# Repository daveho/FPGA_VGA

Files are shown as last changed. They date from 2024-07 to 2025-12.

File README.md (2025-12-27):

# FPGA VGA text display

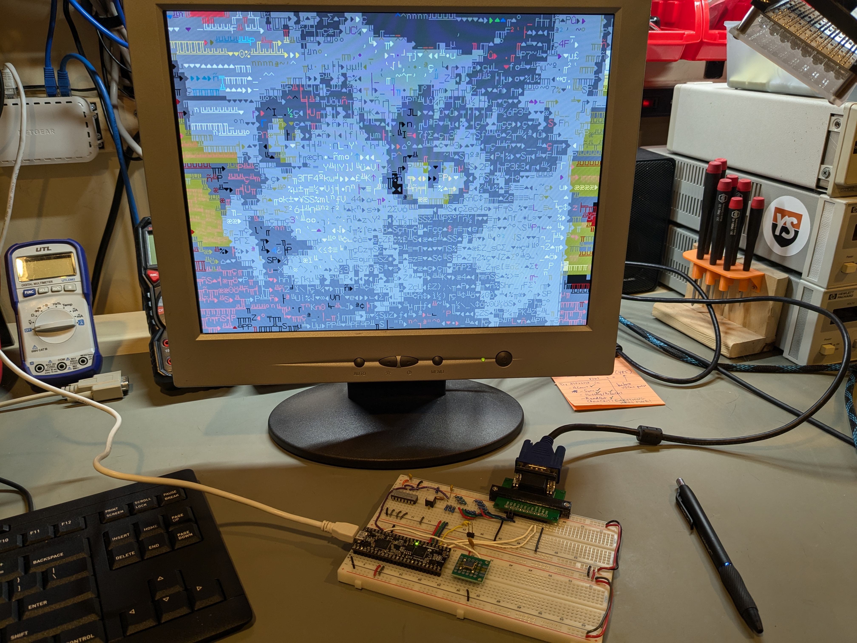
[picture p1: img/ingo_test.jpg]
Photo of FPGA displaying a cat picture rendered with text characters


This is a companion project to the [HW\_VGA](https://github.com/daveho/HW_VGA) project.
Its goal is to implement an 80x30 text display using 640x480 VGA, using more or less
the same approach as the HW\_VGA project, but using a
[Lattice UP5K FPGA](https://www.latticesemi.com/en/Products/FPGAandCPLD/iCE40UltraPlus)
on an [Upduino 3.1](https://tinyvision.ai/products/upduino-v3-1) (or 3.0) board
rather than discrete logic, GALs, and dual port static RAM.

As of December 2025, the design is fully working. I made a video about it:
<https://youtu.be/PG1XWQCylTA>.

The [Schematic](Schematic) directory has a KiCad schematic, and the
[Logic](Logic) directory has the Verilog code for the FPGA. I use
[APIO](https://github.com/FPGAwars/apio) as the front end for the FPGA tools (see my
[blog post about using the Upduino 3 on Linux](https://daveho.github.io/2021/02/07/upduino3-getting-started-on-linux.html)
for details on setting things up.)

Acknowledgment: a viewer of one of my youtube videos recommended
[John Winans's youtube channel](https://www.youtube.com/channel/UCik0xMsb7kSpPUvT2JoJQ1w)
as a good starting point for learning about FPGA development.
His [introduction to simulation](https://youtu.be/xZhl64vHJ-E)
and [his Verilog examples repo](https://github.com/johnwinans/Verilog-Examples) were
incredibly helpful. By applying the techniques covered in the simulation video, I
basically went from having no idea how to simulate designs to being able to write
some halfway-reasonable testbenches in a day or two. Thank you, John!

## Updates

**27-Dec-2025**: A [Youtube video](https://youtu.be/PG1XWQCylTA) about the
project has been posted.

**25-Nov-2025**: the entire design, including a bidirectional
interface to allow the host system to write to and read from VRAM,
appears to be fully working. Video coming soon. Stay tuned!

**20-Nov-2025**: In my previous thoughts about using mirrored VRAM
banks, I had forgotten that I was using 4 KB of block RAM to store
the VGA font. So, the revised plan is mirrored
[5 KB banks](https://github.com/daveho/FPGA_VGA/blob/90469b43ef998fe6521666e1b50f645583a588a4/Logic/vram_5kb.v)
of VRAM.  With the 4 KB of block RAM used for the font, this means
that we're using 2×5 + 4 = 14 KB, which is just under the 15 KB of
block RAM that the Upduino 3's UP5K FPGA has available.

**17-Nov-2025**: Reading an article on Hacker News about an
[FPGA implementation of the IBM PC-XT](https://bit-hack.net/2025/11/10/fpga-based-ibm-pc-xt/)
gave me a really good idea about how to work around the single
read port on the ICE40 Block RAM. The idea is to use two separate
memory banks for the VRAM. Writes from the host system
go to both banks in parallel, so their contents are always identical.
The display rasterization hardware reads from one bank, and the
host system (when it wants to read from VRAM) reads from the other
bank. This would allow for VRAM with one write port and two
fully-independent read ports. One minor difficulty is that the
UP5K device on the Upduino 3 has only 15 KB of VRAM, whereas the
current design uses 8 KB for VRAM. The 80x30 character display
needs only 4800 bytes, so reducing the VRAM to 6 KB would be sufficient.
A 6 KB VRAM bank could be implemented as a 4 KB lower bank and a
2 KB upper bank, mapped into an 8 KB address space with the upper
2 KB bank mirrored twice in the upper 4 KB of addresses. This wouldn't
cause any problems in practice. I'm planning to work on this soon
(maybe over Thanksgiving.)

**8-Aug-2024**: the block RAM in the ICE40 UP5K FPGA used in the
Upduino 3.0/3.1 is not true dual port memory, which will make the host interface
implementation a bit more complicated than I originally envisioned,
since the pixel generator and the host interface will need to share
the single hardware read port to the video memory. So, it may be a while
before I get this working.

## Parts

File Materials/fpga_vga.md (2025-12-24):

---
title: "Episode 5 (Hardware VGA, FPGA edition!)"
aspectratio: 169
colorlinks: true
pandoc-beamer-block:
  - classes: [info]
  - classes: [alert]
    type: alert
pandoc-latex-fontsize:
  - classes: [small]
    size: small
  - classes: [footnotesize]
    size: footnotesize
  - classes: [scriptsize]
    size: scriptsize
header-includes:
  - \usepackage{graphbox}
  - \usepackage[export]{adjustbox}
  - \usepackage[absolute,overlay]{textpos}
  - \usecolortheme{orchid}
---

## Hello again! {.t}

Since 2016, I've been working on a 6809-based microcomputer system `\pause`{=latex}

Summer 2024[^*]: I made a VGA text display using GALs,
dual port static RAMs, and 7400-series logic chips `\pause`{=latex}

Validated the design by simulating in Logisim Evolution `\pause`{=latex}

Got it to work! `\pause`{=latex}

Lots of fun, great learning experience `\pause`{=latex}

*Not very practical* `\pause`{=latex}

* Resulting design has 25 ICs, including two
  52-pin PLCC packages `\pause`{=latex}
* Even using surface mount ICs, very challenging
  to fit on 15cm by 9cm PCB

[^*]: In North America

## Use an FPGA? {.t}

The obvious move would be to use an FPGA `\pause`{=latex}

I've stuggled for *years* to learn FPGAs well enough to make
a display controller `\pause`{=latex}

But...I now had a working design, even if not
an FPGA-based design `\pause`{=latex}

* **Maybe I could translate it to Verilog** `\pause`{=latex}

TL;DR I translated the design to Verilog `\pause`{=latex}

This video: `\pause`{=latex}

* Translating the design to Verilog (the easy parts) `\pause`{=latex}
* Host interface (initially got stuck here, then
  learned about an easy workaround) `\pause`{=latex}
* Demo `\pause`{=latex}
* Next steps `\pause`{=latex}

As always, links to the code and schematic are in the video description.

## Modules {.t}

The original design had 6 modules, each implemented as a GAL
(or two GALs in the case of the pixel generator) and,
where necessary, supporting ICs:

Module              | GAL equations
------------------- | -------------
Horizontal count    | HCntCtrl.pld
Vertical count      | VCntCtrl.pld
Sync generation     | Sync.pld
Readout address gen | ROutCtrl.pld
VRAM                | VRAMCtrl.pld
Pixel gen           | PxGnCtrl.pld, ShiftReg.pld

## Modules (FPGA) {.t}

In the FPGA version of the design, each module is implemented
by one Verilog module:

Module              | GAL equations               | Verilog
------------------- | --------------------------- | -----------
Horizontal count    | HCntCtrl.pld                | hcount.v
Vertical count      | VCntCtrl.pld                | vcount.v
Sync generation     | Sync.pld                    | sync.v
Readout address gen | ROutCtrl.pld                | readout.v
VRAM                | VRAMCtrl.pld                | vram\_mirrored.v
Pixel gen           | PxGnCtrl.pld, ShiftReg.pld  | pixgen.v

`\pause`{=latex} To convert the design to Verilog, I translated the
logic in the original GAL equations and the supporting ICs to
equivalent Verilog constructs in the most direct way possible.

## Converting to Verilog {.t}

General approach to conversion to Verilog:`\pause`{=latex}

Original Design | Verilog
--------------- | --------------- 
GAL registers, 7400 series registers (e.g., 74ALS273) | `reg` instances
Counters (e.g., 74ALS163)            | `reg` instances (Verilog supports addition!)
Clock data into a flip flop          | Nonblocking assignment in `always` block
Dual port RAM (IDT7134)              | Array of 8-bit registers inferred as BRAM
Font ROM (27SF512)                   | 4 KB of pre-initialized block RAM
Module inputs and outputs            | Module inputs and outputs

`\pause `{=latex} Overall, this wasn't too hard!

<!--
* GAL registers and 7400 series registers (e.g., 74ALS273)
  become Verilog registers (`reg` instances) `\pause`{=latex}
* Counters (e.g., 74ALS163) also become Verilog registers
  (because Verilog supports addition, e.g. `addr + 13'd1;`)
  `\pause`{=latex}
* Clocking data into a flip flop becomes a nonblocking assignment
  in an `always @( posedge clk )` block `\pause`{=latex}
* An array of 8-bit vectors with suitable read and write signaling
  will be inferred as block RAM: takes place of dual port static
  RAM (IDT7134) `\pause`{=latex}
* Input and output pins become module input and output wires
-->

## Example: Horizontal Count module {.t}

The horizontal count module counts the horizontal pixels in each
scanline, and generates appropriate timing signal needed by
the vertical count and sync generation modules

In the original implementation:

* 3x 74ALS163 4-bit counters
* GAL for control and timing`\\`{=latex}
  signal generation

`\vfill`{=latex}

Example timing signal: horizontal count`\\`{=latex}
end (true if horizontal count value is at`\\`{=latex}
maximum for scanline)

``` { .scriptsize }
; HCOUNT_END is when HCOUNT=799 (1100011111 binary)
HCEND   = HC9 * HC8 * /HC7 * /HC6 * /HC5 * HC4 * HC3 * HC2 * HC1 * HC0
```

## Example: Horizontal Count module {.t}

In Verilog: define a 12-bit register, reset or increment it as needed:

```verilog { .scriptsize }
reg [11:0] count;

always @(posedge clk) begin
  if ( nrst == 1'b0 ) begin
    // in reset, clear the counter
    count <= 12'd0;
  end else begin
    // not in reset, either advance count by 1 or reset to 0 (if at end of scanline)
    if ( hCountEnd )
      count <= 12'd0;
    else
      count <= count + 12'd1;
  end
end
```

Generating a control signal:

```verilog { .scriptsize }
assign hCountEnd = (count == H_COUNT_END);
```

## Example: Sync module {.t}

The Sync module uses control signals generated by the horizontal
and vertical count modules to generate to generate VGA horizontal
and vertical sync signals, as well as visibility and ``activity''
signals needed by the pixel generator and readout modules.

In the original implementation, it's a single GAL22V10
with registered outputs.

`\vfill`{=latex}

Example timing signal: VGA vertical sync

``` { .scriptsize }
; Vertical sync:
;   - if /NRST is asserted, next VSync should be high
;   - if VEPulse is asserted, next VSync should be high
;   - if neither VBPulse nor VEPulse is asserted, next VSync value
;     should be the same as the current one
VSync.R =   /NRST
          + VEPulse
          + /VBPulse * /VEPulse * VSync
```

## Example: Sync module {.t}

In Verilog, generated outputs are `reg` instances:

```verilog { .scriptsize }
// registers for registered outputs
reg hSyncReg, vSyncReg, hVisReg, vVisReg, vActiveReg;
```

Their contents are updated on each positive clock edge:

```verilog { .scriptsize }
// Note: only showing vSyncReg updates
always @( posedge clk ) begin
  if ( nrst == 1'b0 ) begin
    vSyncReg <= 1'b1; // in reset
  end else begin
    // update vSyncReg if needed
    if ( vBeginPulse ) begin
      vSyncReg <= 1'b0; // begin vsync pulse
    end else if ( vEndPulse ) begin
      vSyncReg <= 1'b1; // end vsync pulse
    end
  end
end
```

## Example: Readout module {.t}

::: columns

:::: column

::::: {.small}
The Readout module generates the VRAM addresses of the character
and attribute values needed to generate the pixels for each visible
scanline.

Original implementation: 3 74ALS163 counters (current address),
2 74ALS273 registers (row begin address), GAL22V10 for control.

* Row of characters = 160 bytes (80 char/attr pairs)
* Characters are 8 pixels wide
* Update readout addr every 4 pixels
* Same sequence of addresses for each
  scanline in a character row

Annoyance: VRAM addresses are 13 bits, so the GAL generates the
MSB of the current address. (Each '163 is only 4 bits.)

:::::

::::

:::: column

`{\ }`{=latex}

::::

:::

## Example: Readout module {.t}

In Verilog, the row begin address and current (readout) address
are just 13 bit registers:

```verilog { .scriptsize }
reg [12:0] rowBeginAddrReg;
reg [12:0] readoutAddrReg;
```

Conditionally update their values according to current control
signal values:

```verilog { .scriptsize }
// Example logic: update rowBeginAddrReg or readoutAddrReg
// at end of scanline (when hSync pulse starts)
if ( vActive & hBeginPulse ) begin
  if ( vCount == 4'b1111 ) begin
    // We've reached the last pixel row in the current character row,
    // so set the row begin address to the current readout address
    // (in order to start the next character row)
    rowBeginAddrReg <= readoutAddrReg;
  end else begin
    // The next pixel row will be part of the same character row,
    // so set the readout address back to the current value of the
    // row begin address register.
    readoutAddrReg <= rowBeginAddrReg;
  end
end
```

## Aside: Verilog test benches {.t}

A viewer of a previous video suggested that I check out
the John's Basement youtube channel to learn about simulation. `\pause`{=latex}

"Test bench" = unit tests for a module (or maybe several modules
working together) `\pause`{=latex}

* Feed in simulated clock and control signals, verify that
  correct output signals are generated `\pause`{=latex}

**This was very, very helpful!** `\pause`{=latex}

I wrote test benches for the Horizontal Count, Vertical Count,
and Readout modules. (Testing Readout indirectly tests Sync.)
This helped me gain confidence that the design would work when
uploaded to the FPGA.

## So, everything was easy, right? {.t}

Well...`\pause `{=latex}**There was one problem**

`\pause `{=latex} The UP5K FPGA's block RAM is`\pause`{=latex}

* Synchronous (not a problem) `\pause`{=latex}
* Not truly dual ported (**big problem!**) `\pause`{=latex}

IDT7134 static RAMs (original design) are true dual port memory `\pause`{=latex}

* Each port can read and write as necessary `\pause`{=latex}
* Rasterization hardware needs to read from VRAM `\pause`{=latex}
* Host system needs to read/write VRAM `\pause`{=latex}
* *No problem, they each use one port* `\pause`{=latex}

UP5K block RAMs have one read port and one write port `\pause`{=latex}

* *Rasterization hardware and host system both want the read port!* `\pause`{=latex}

**What to do?**

## Initial idea: time-share the read port {.t}

Rasterization hardware only reads VRAM 1 out of 4 clock cycles `\pause`{=latex}

Could use the other clock cycles to allow the host system to read `\pause`{=latex}

Not a terrible idea, but significantly complicates the design `\pause`{=latex}

* I made some attempts, but they didn't work `\includegraphics[width=1em]{figures/fpga_vga/angry_face.pdf}`{=latex}

## Genius idea {.t}

*When in doubt, use brute force* — Ken Thompson `\pause`{=latex}

When reading Hacker News I saw a link to a project to create
an FPGA implementation of the IBM PC-XT `\pause`{=latex}

Awesome idea: maintain two copies of video memory `\pause`{=latex}

* Writes from host system go to both (so they always have
  the same content) `\pause`{=latex}
* Rasterization hardware reads from one copy `\pause`{=latex}
* Host system reads from the other copy `\pause`{=latex}

We get a second read port with minimal effort `\pause`{=latex}

* At the cost of doubling the amount of block RAM used `\pause`{=latex}
* Good tradeoff when the limiting factor is the skill of the
  designer `\includegraphics[width=1.2em]{figures/fpga_vga/laughing.pdf}`{=latex}

## Utilizing block RAM {.t}

The UP5K has 15 KB of block RAM `\pause`{=latex}

We need 4 KB for the font, so 11 KB is left for VRAM `\pause`{=latex}

Original design: 2 x IDT7134, 8 KB total VRAM `\pause`{=latex}

In the FPGA-based design, mirrored 5 KB banks requiring
a total of 10 KB `\pause`{=latex}

* Each 5 KB bank is really 4 KB + 1 KB, with the 1 KB
  mirrored 4 times in the upper 4 KB of VRAM addresses `\pause`{=latex}

Overall, this was pretty easy to implement

* `vram_5kb.v`: Verilog module implementing one 5 KB VRAM bank
* `vram_mirrored.v`: Verilog module using two `vram_5k` instances
  to implement a 5 KB VRAM with one write port and two read ports
  `\pause`{=latex}

The readout and pixel generator modules did not need any modification

## Host system reads and writes {.t}

Now I just needed the actual host interface `\pause`{=latex}

Goal: make the display controller's framebuffer look like a normal
asynchronous static RAM

Signals: `\pause`{=latex}

* Bidirectional 8-bit data bus interface `\pause`{=latex}
* 13-bit address input `\pause`{=latex}
* Read strobe input: assert to read byte from VRAM `\pause`{=latex}
* Write strobe input: assert to write byte to VRAM `\pause`{=latex}

Problem: how does bidirectional I/O work in Verilog?

## Bidirectional I/O {.t}

In an old-school microcomputer system: `\pause`{=latex}

* CPU and all peripheral chips connect to a shared parallel data bus `\pause`{=latex}
* Only the chip that is "talking" actively drives the bus `\pause`{=latex}
* All others "tristate" their connections to the data bus `\pause`{=latex}
* Peripherals have an "output enable" of some sort to tell them when
  they can drive output on the data bus `\pause`{=latex}

FPGAs don't use tristate logic internally (AFAIA) `\pause`{=latex}

Synthesis tools create muxes whenever multiple outputs influence
a single input `\pause`{=latex}

Verilog does have a syntax for tristate logic (e.g., `1'bz` to mean a
"high impedence" logic value) `\pause`{=latex}

* But OSS CAD suite (Yosys, ICEStorm, etc.) doesn't really support Verilog
  tristate logic

## What I needed {.t}

What I needed was `\pause`{=latex}

* If host asserts the write strobe, store the data on the bus
  to VRAM (data bus is input) `\pause`{=latex}
* If host asserts the read strobe, drive one VRAM data byte onto
  the data bus (data bus is output) `\pause`{=latex}

How to tell the synthesis to make this happen? `\pause`{=latex}

Did some initial research, wasn't sure how to proceed

## John's Basement to the rescue again {.t}

Found a video on John's Basement covering the ICE40
`SB_IO` primitive `\pause`{=latex}

* Configures an external pin for I/O, including bidirectional I/O `\pause`{=latex}
* For bidirectional I/O, you specify physical pin and
  output enable, it gives you an input and output

## Implementing the host interface {.t}

`ext_data_bus.v` module: one `SB_IO` instance per data bus pin `\pause`{=latex}

E.g.:

```verilog { .scriptsize }
  SB_IO #(
    .PIN_TYPE(6'b1010_01),
    .PULLUP(1'b1)
  ) ext_pin_0 (
    .PACKAGE_PIN(phys[0]),
    .OUTPUT_ENABLE(outputEnable),
    .D_OUT_0(outToBus[0]),
    .D_IN_0(inFromBus[0])
  );
```

 `\pause `{=latex} Output enable is simply the read strobe! `\pause`{=latex}

Read strobe, write strobe, and data bus directly interface to the VRAM `\pause`{=latex}

VGA dot clock (used for synchronous block RAM reads/writes) is fast,
host access should work as long as there is one dot clock edge
during a bus transfer

## Does it work? {.t}

At this point I had what I thought was a viable host interface `\pause`{=latex}

**Would it actually work?**

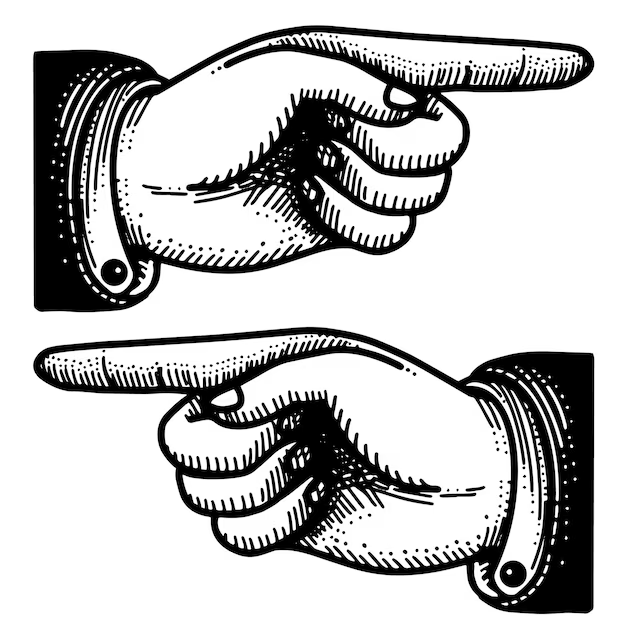
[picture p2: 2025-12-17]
Materials/img/hand.png

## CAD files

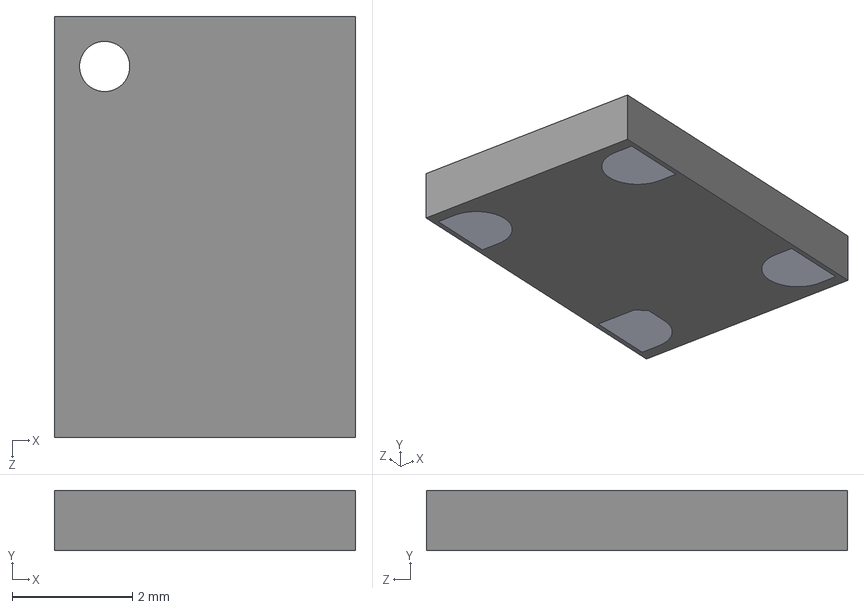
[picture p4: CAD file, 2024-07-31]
Schematic/SIT8208AI-8F-33E-14.745600Y.step
5.00 x 1.00 x 7.00 mm

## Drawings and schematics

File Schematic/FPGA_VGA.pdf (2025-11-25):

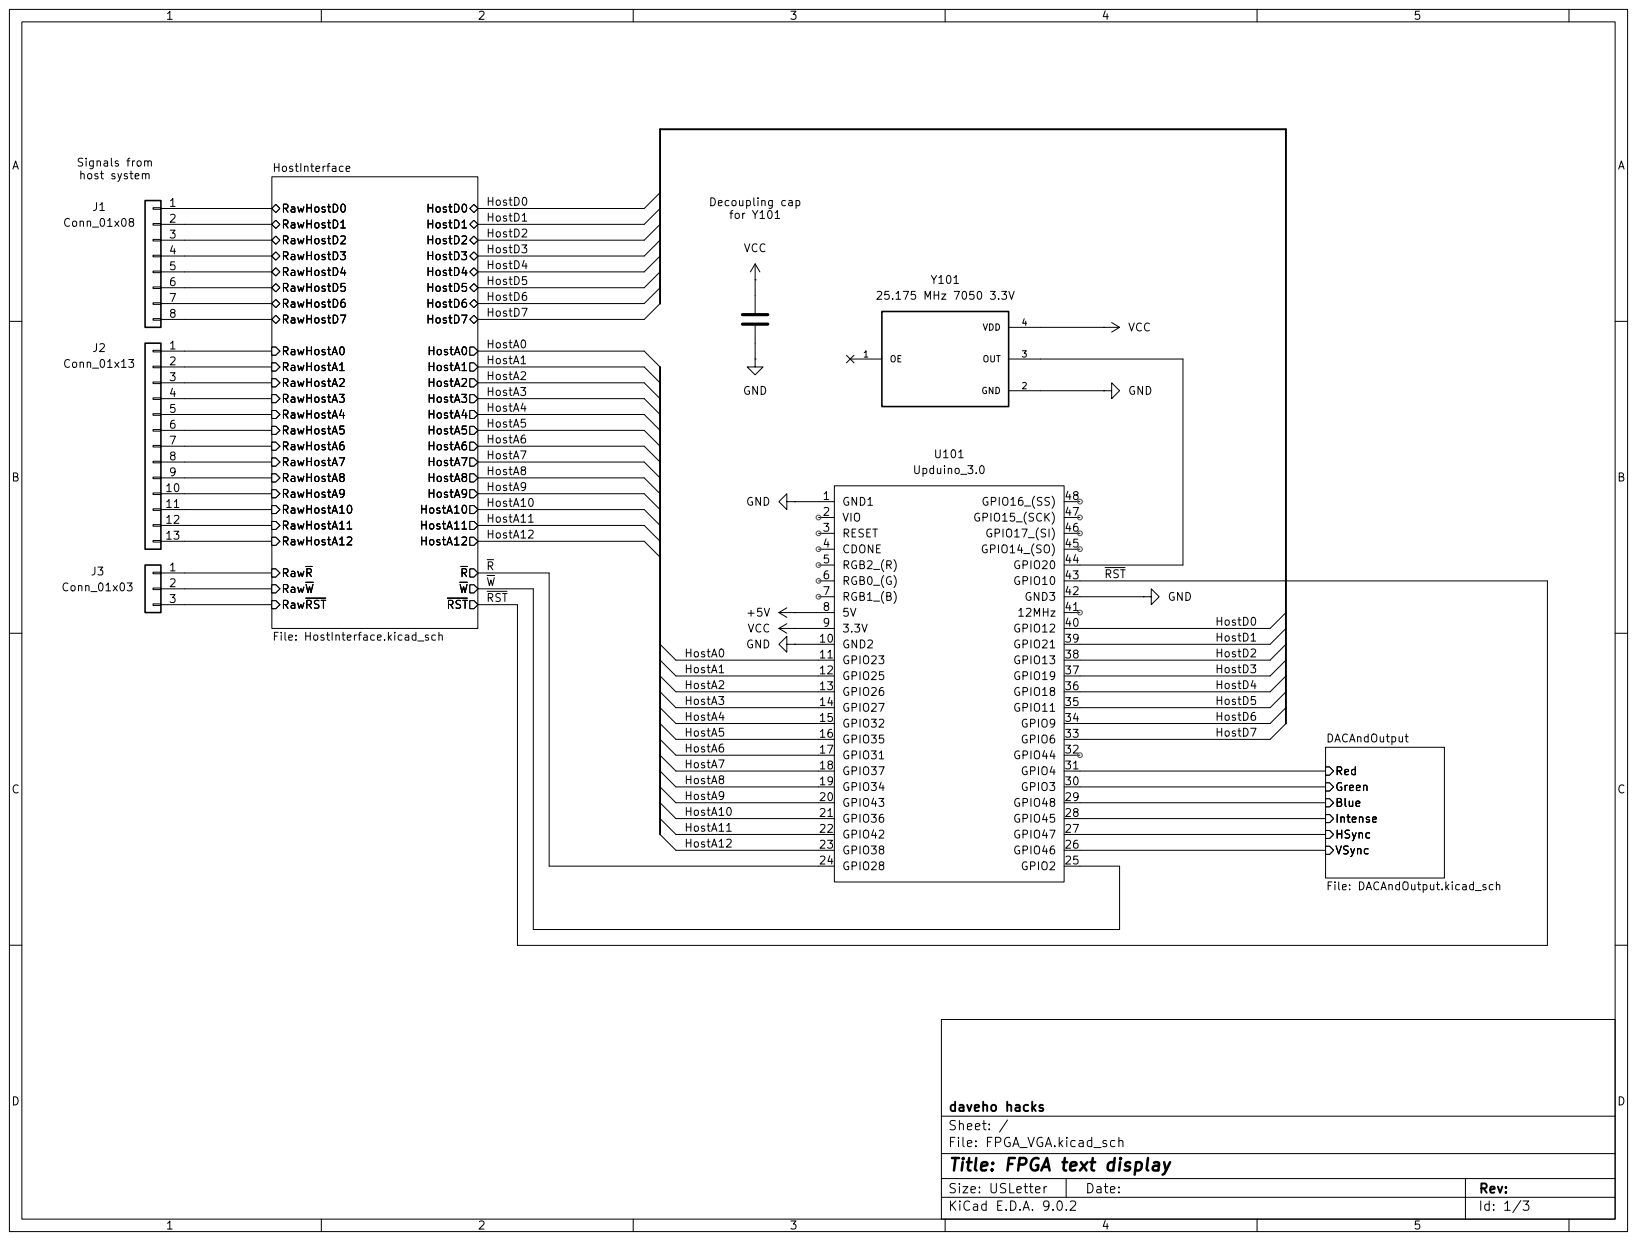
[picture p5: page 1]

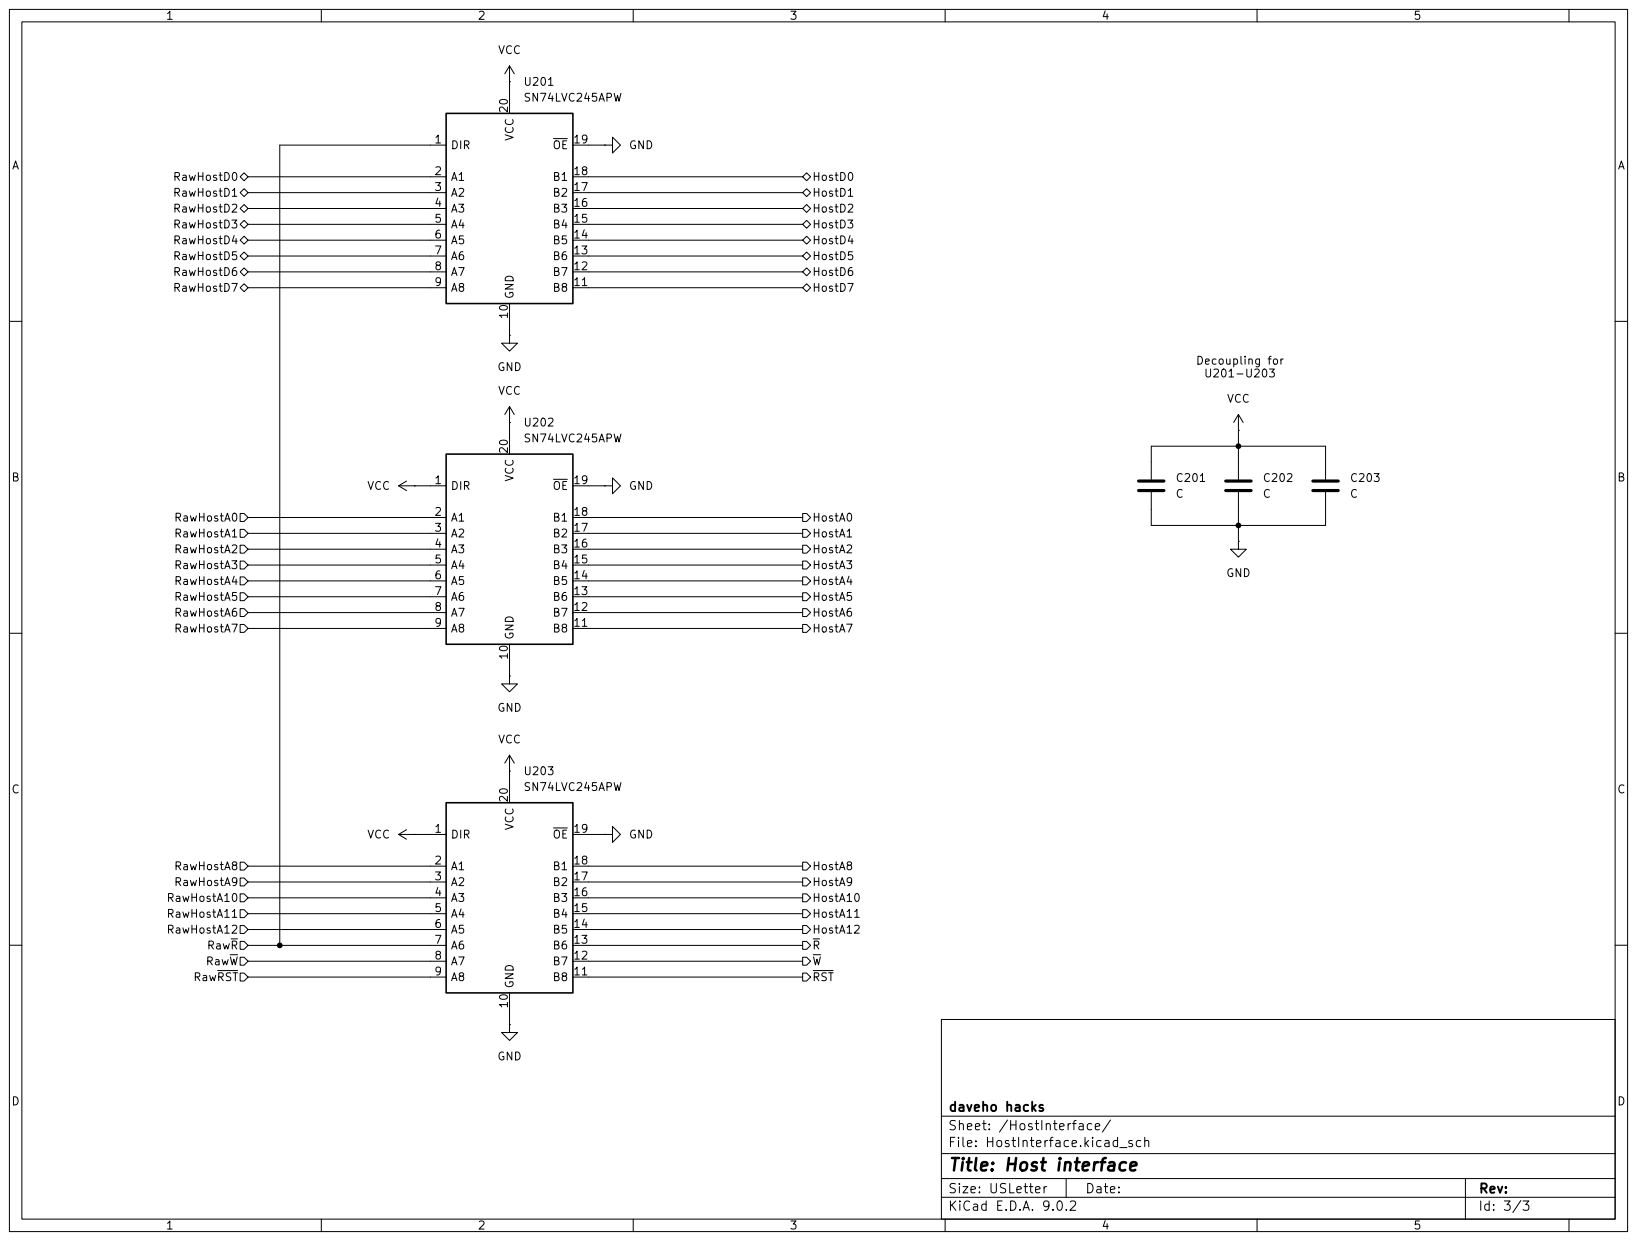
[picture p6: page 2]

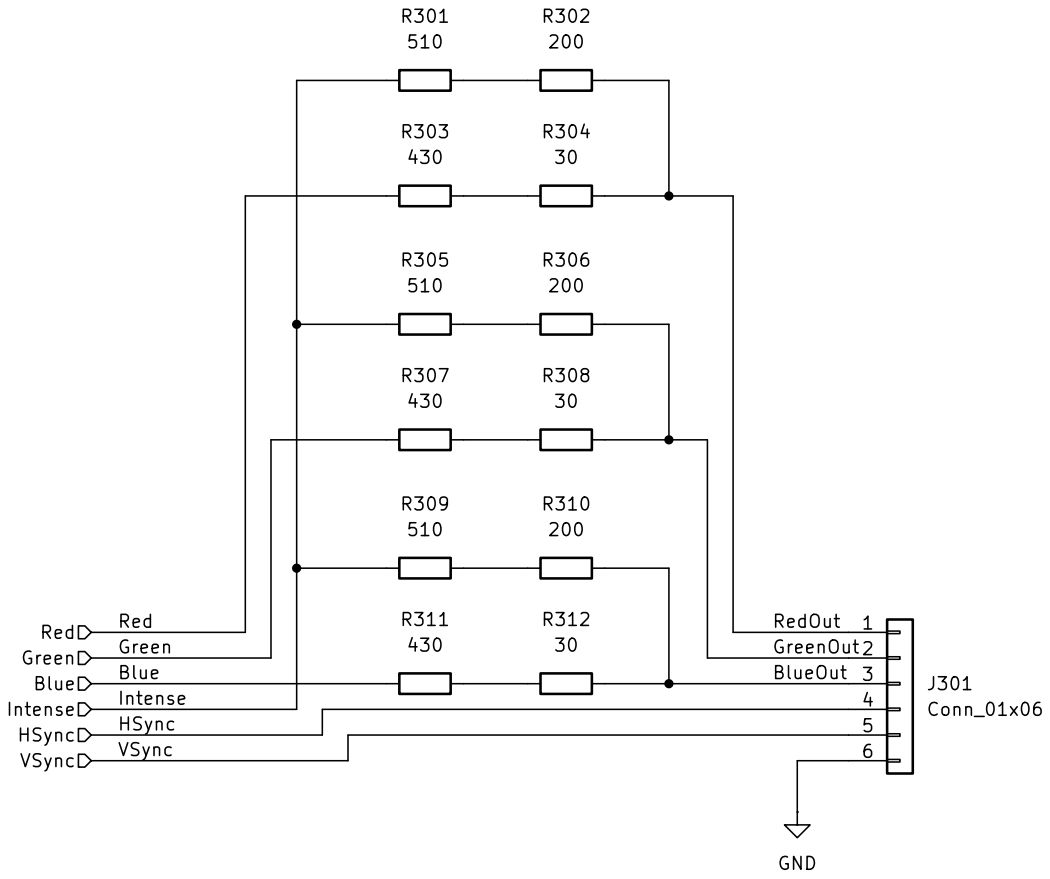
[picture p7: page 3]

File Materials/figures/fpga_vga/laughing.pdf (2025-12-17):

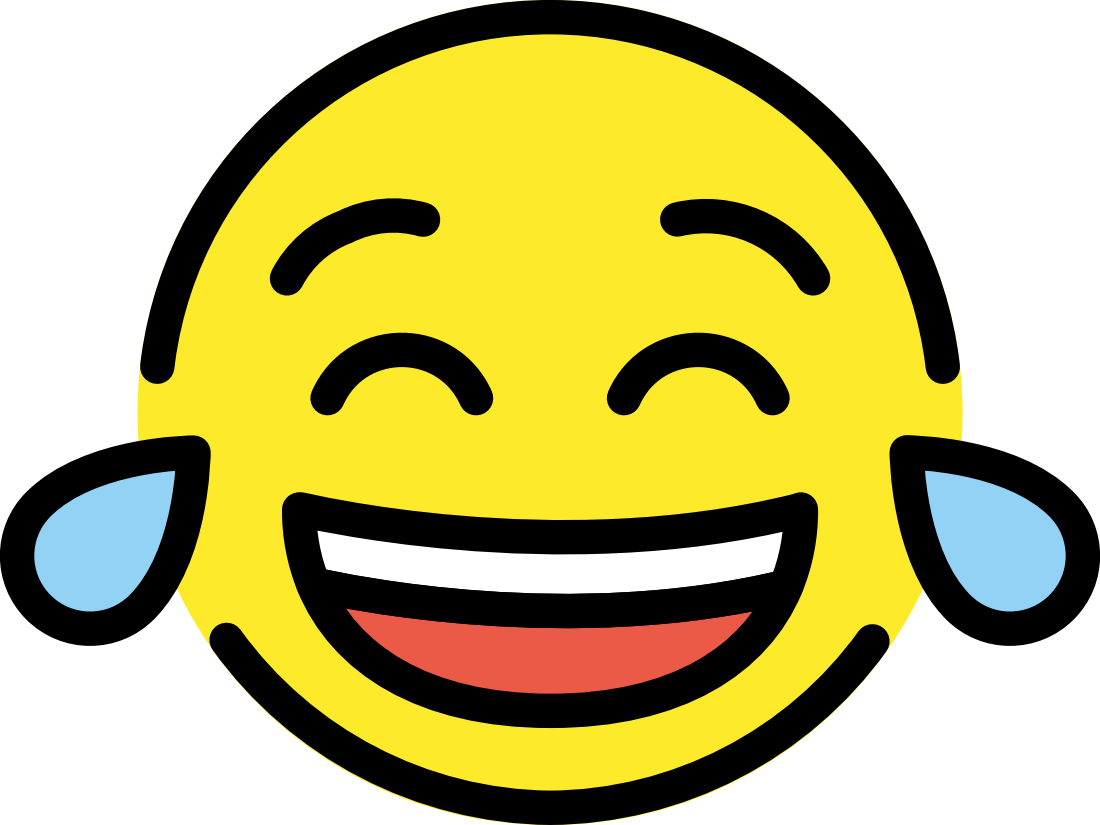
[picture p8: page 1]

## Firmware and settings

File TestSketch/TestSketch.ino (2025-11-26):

// Test program for VGA display

// There are 2 74HC595 shift registers used to generate
// the address for display VRAM reads/writes

// Connections
//   Arduino D[7:0] (AVR PORTD) connected to display data bus (D[7:0])
//     Allows reading and writing bytes of data from/to the display VRAM
//   Arduino D8: connected to serial data input of first shift register
//   Arduino D9: serial clock output to shift registers
//     (data shifted on positive edge)
//   Arudino D10: register clock output to shift register
//     (data clocked into output registers on positive edge)
//   Arduino D11: output to display -R (read strobe)
//   Arduino D12: output to display -W (write strobe)
//   Arduino D13: output to display -RST (reset)
//   Arduino D14: pushbutton input (0=pressed), used to start the tests
//   Arduino D15: output to green LED (if tests pass)
//   Arduino D16: output to red LED (if tests fail)

#define PIN_SER_DATA  8
#define PIN_SER_CLK   9
#define PIN_SER_RCLK  10
#define PIN_NR        11
#define PIN_NW        12
#define PIN_NRST      13
#define PIN_BTN       14
#define PIN_GREEN_LED 15
#define PIN_RED_LED   16

// Set the display address.
void setAddr( uint16_t addr ) {
  // address bits are sent to shift register from MSB to LSB
  for ( int i = 0; i < 16; ++i ) {
    int bit = ( addr & 0x8000 ) != 0 ? HIGH : LOW;
    // output the bit
    digitalWrite( PIN_SER_DATA, bit );
    // clock it in
    digitalWrite( PIN_SER_CLK, HIGH );
    digitalWrite( PIN_SER_CLK, LOW );
    // go to next bit
    addr <<= 1;
  }
  // Clock data into the output register
  digitalWrite( PIN_SER_RCLK, HIGH );
  digitalWrite( PIN_SER_RCLK, LOW );
}

void writeVRAM( uint16_t addr, uint8_t byte ) {
  setAddr( addr ); // assert address to write to
  DDRD = 0xFF; // set port D pins to output
  PORTD = byte;
  digitalWrite( PIN_NW, LOW ); // start write pulse
  digitalWrite( PIN_NW, HIGH ); // end write pulse
}

uint8_t readVRAM( uint16_t addr ) {
  setAddr( addr ); // assert address to read from
  DDRD = 0x00;  // set port D pins to input
  PORTD = 0x00; // no pull-ups
  uint8_t data;
  digitalWrite( PIN_NR, LOW ); // start read pulse
  data = PIND; // read byte from data bus
  digitalWrite( PIN_NR, HIGH ); // end read pulse

  // set PORTD pins back to output:
  // avoids leaving the bus transceiver A-side inputs floating
  DDRD = 0xFF;

  return data;
}

#define BLACK   0
#define RED     1
#define GREEN   2
#define YELLOW  3
#define BLUE    4
#define MAGENTA 5
#define CYAN    6
#define GRAY    7
#define INTENSE 8
#define ATTR( fg, bg ) ((bg)|((fg) << 4 ))

// Display text, starting at specified VRAM address
void displayText( uint16_t addr, const char *s, uint8_t attr ) {
  while ( *s != '\0' ) {
    char c = *s;
    ++s;
    writeVRAM( addr, c );
    ++addr;
    writeVRAM( addr, attr );
    ++addr;
  }
}

// Clear the display
void clearDisplay() {
  uint16_t addr = 0;
  for ( int16_t i = 0; i < 2400; ++i ) {
    writeVRAM( addr++, ' ' );
    writeVRAM( addr++, ATTR(GRAY, BLACK) );
  }
}

// Check the result of clearing the display:
// every character should be set to space, and every
// attribute should be set to fg=GRAY bg=BLACK.
bool checkDisplayClear( bool good ) {
  uint16_t addr = 0;
  uint8_t val;
  for ( int i = 0; i < 2400; ++i ) {
    val = readVRAM( addr++ );
    if ( val != ' ' )
      good = false;
    val = readVRAM( addr++ );
    if ( val != ATTR(GRAY,BLACK) )
      good = false;
  }

  return good;
}

#define HELLO_TEXT_ADDR 2314

// Check that the "Hello!" text was written correctly.
bool checkHelloText( bool good ) {
  const char expected[] = "Hello!";
  uint16_t addr = HELLO_TEXT_ADDR;
  uint8_t val;
  for ( int i = 0; i < 6; ++i ) {
    val = readVRAM( addr++ );
    if ( val != expected[i] )
      good = false;
    val = readVRAM( addr++ );
    if ( val != ATTR(YELLOW|INTENSE, BLUE) )
      good = false;
  }
  return good;
}

// Start character and attribute values for test pattern
#define TEST_PATTERN_START_CH   58
#define TEST_PATTERN_START_ATTR 150

// Display a test pattern
void testPattern() {
  uint8_t ch = TEST_PATTERN_START_CH;
  uint8_t attr = TEST_PATTERN_START_ATTR;
  uint16_t addr = 0;

  for ( int i = 0; i < 2400; ++i ) {
    writeVRAM( addr++, ch++ );
    writeVRAM( addr++, attr++ );
  }
}

// Check that VRAM contains expected contents of test pattern
bool checkTestPattern( bool good ) {
  uint8_t expected_ch = TEST_PATTERN_START_CH;
  uint8_t expected_attr = TEST_PATTERN_START_ATTR;
  uint16_t addr = 0;

  for ( int i = 0; i < 2400; ++i ) {
    uint8_t val;
    val = readVRAM( addr++ );
    if ( val != expected_ch )
      good = false;
    ++expected_ch;
    val = readVRAM( addr++ );
    if ( val != expected_attr )
      good = false;
    ++expected_attr;
  }

  return good;
}

void successDisplay() {
  clearDisplay();
  displayText( 1022, "All tests passed!", ATTR(GREEN|INTENSE, BLACK) );
  displayText( 2588, "Writing to VRAM and reading from VRAM appear to work", ATTR(YELLOW|INTENSE, BLUE) );
  displayText( 2942, "LET'S FRICKIN' GO", ATTR(CYAN|INTENSE, BLACK) );
}

void runTests() {
  // turn off green and red LEDs
  digitalWrite( PIN_GREEN_LED, LOW );
  digitalWrite( PIN_RED_LED, LOW );

  // Generate a reset pulse for the display controller
  digitalWrite( PIN_NRST, LOW );
  delay( 1 );
  digitalWrite( PIN_NRST, HIGH );

  bool good = true;

  clearDisplay();
  good = checkDisplayClear( good );
  displayText( 2314, "Hello!", ATTR(YELLOW|INTENSE, BLUE) );
  good = checkHelloText( good );

  delay( 1000 ); // let hello message be visible for one second

  testPattern();
  good = checkTestPattern( good );

  delay( 1000 ); // let test pattern be visible for one second

  // If tests passed, display success text
  if ( good )
    successDisplay();

  // Turn on green or red LED
  digitalWrite( good ? PIN_GREEN_LED : PIN_RED_LED, HIGH );

  // wait for a bit
  delay( 10 );
}

void setup() {
  // Initial state

  // PORTD configured as output
  // D8-D13 configured as output
  // D14 configured as input with pullup
  // D15-D16 configured as output

  DDRD = 0xFF;
  pinMode( PIN_SER_DATA, OUTPUT );
  pinMode( PIN_SER_CLK, OUTPUT );
  pinMode( PIN_SER_RCLK, OUTPUT );
  pinMode( PIN_NR, OUTPUT );
  pinMode( PIN_NW, OUTPUT );
  pinMode( PIN_NRST, OUTPUT );
  pinMode( PIN_BTN, INPUT_PULLUP );
  pinMode( PIN_GREEN_LED, OUTPUT );
  pinMode( PIN_RED_LED, OUTPUT );

  // Drive serial data and register clocks low
  digitalWrite( PIN_SER_CLK, LOW );
  digitalWrite( PIN_SER_RCLK, LOW );

  // De-assert -R, -W, -RST
  digitalWrite( PIN_NR, HIGH );
  digitalWrite( PIN_NW, HIGH );
  digitalWrite( PIN_NRST, HIGH );

  // Turn off LEDs
  digitalWrite( PIN_GREEN_LED, LOW );
  digitalWrite( PIN_RED_LED, LOW );

  // Wait for a bit
  delay( 2 );
}

void loop() {
  for (;;) {
    if ( digitalRead( PIN_BTN ) == LOW ) {
      // button pressed, so run the tests
      runTests();
    }
  }
}

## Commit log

2024-07-31 DAC simulation (for 3.3V VCC)
2024-07-31 start schematic and verilog code
    [FPGA_VGA.kicad_pcb, FPGA_VGA.kicad_sch]
2024-07-31 added resistor DAC and VGA connector
    [FPGA_VGA.kicad_sch]
2024-07-31 added oscillator, fix wiring to DAC and VGA conn
    [FPGA_VGA.kicad_sch, SIT8208AI-8F-33E-14.745600Y.step]
2024-08-01 vcount testbench is pretty reasonable
    It basically ticks through one frame and verifies that
    the appropriate timing signals are generated. The TICK
    macro now keeps track of the number of ticks, which is
    helpful for making assertions about exact timing.
    Probably the testbench could go further in verifying
    exact timing.
2024-08-02 factor schematic and FPGA logic into subdirs
    [FPGA_VGA.kicad_pcb, FPGA_VGA.kicad_sch, SIT8208AI-8F-33E-14.745600Y.step]
2024-08-04 start to add level translators for host interface
    [FPGA_VGA.kicad_sch]
2024-08-04 added a host interface
    Also, modularized the schematic.
    [DACAndOutput.kicad_sch, FPGA_VGA.kicad_sch, HostInterface.kicad_sch]
2024-08-04 PDF of schematic
2024-08-06 VSync and HSync were mixed up going to output
    [FPGA_VGA.kicad_sch]
2024-08-06 change host bus signal names to match logic
    This was a bit of a tedious change, but I think it's
    worthwhile to make it more obvious how the logic
    and schematic relate to each other.
    [FPGA_VGA.kicad_sch, HostInterface.kicad_sch]
2024-08-06 connect FPGA 5V pin to host +5V
    [FPGA_VGA.kicad_sch]
2024-08-06 VRAM is inferred as 32 block RAMs?
    I'm not sure why, it should only require 16.
    Initially I thought the problem was that the font memory
    wasn't being inferred as block RAM, so I added an unused
    write interface in case Yosys was confused by the font
    memory only being accessed from the read side.
2025-11-18 redesigning host interface
    I think we will be able to do bidirectional I/O on
    external pins, in order to communicate with the host
    data bus.
    Eliminating the bank register as part of the actual
    display controller. Eventually I want the VRAM to be
    mapped into a single 8 KB window. If the host system
    needs a bank register, it can be external to the
    display controller.
    [DACAndOutput.kicad_sch, FPGA_VGA.kicad_sch]
2025-11-18 remove old host interface schematic
    [HostInterface.kicad_sch]
2025-11-18 more prep for re-adding host interface
    [FPGA_VGA.kicad_sch]
2025-11-19 working on host interface / level translation
    [FPGA_VGA.kicad_sch, HostInterface.kicad_sch]
2025-11-19 done with host interface?
    [FPGA_VGA.kicad_sch, HostInterface.kicad_sch]
2025-11-22 updates to schematic preferences
2025-11-22 updated PDF of schematic
2025-11-23 start Arduino test sketch
    This will test writing to and reading from the display VRAM
2025-11-28 note about links to code and schematics
2025-11-29 ignore rendered frames
2025-11-30 start working on Verilog conversion material
2025-12-02 a couple minor additions
